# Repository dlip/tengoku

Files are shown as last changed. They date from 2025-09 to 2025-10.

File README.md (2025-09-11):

# Tengoku

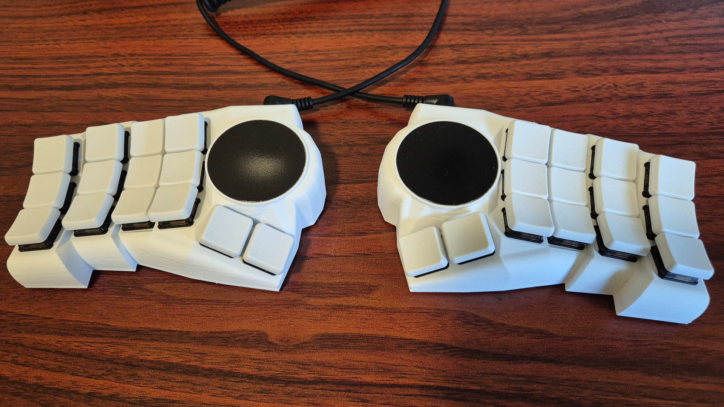
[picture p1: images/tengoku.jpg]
tengoku


28 Key Keyboard with dual trackpads made using [Cosmos Keyboard Generator](https://ryanis.cool/cosmos/beta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)

[Build Guide](/build.md)

## Media

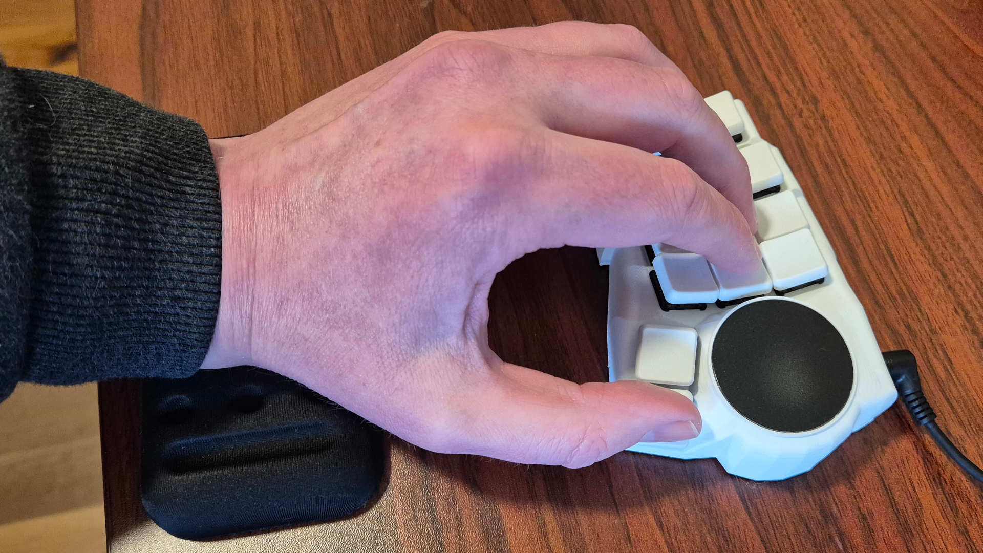
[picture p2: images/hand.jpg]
Hand size


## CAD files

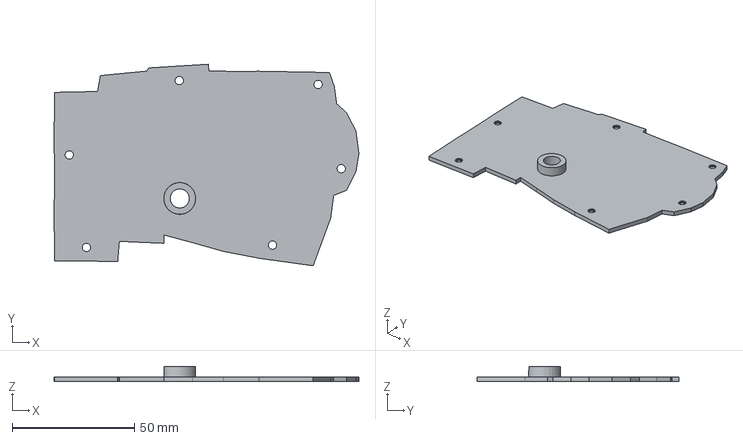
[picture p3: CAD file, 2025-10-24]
cad/tengoku-plateleft-with-mount-hole.step
124.7 x 82.4 x 6.30 mm

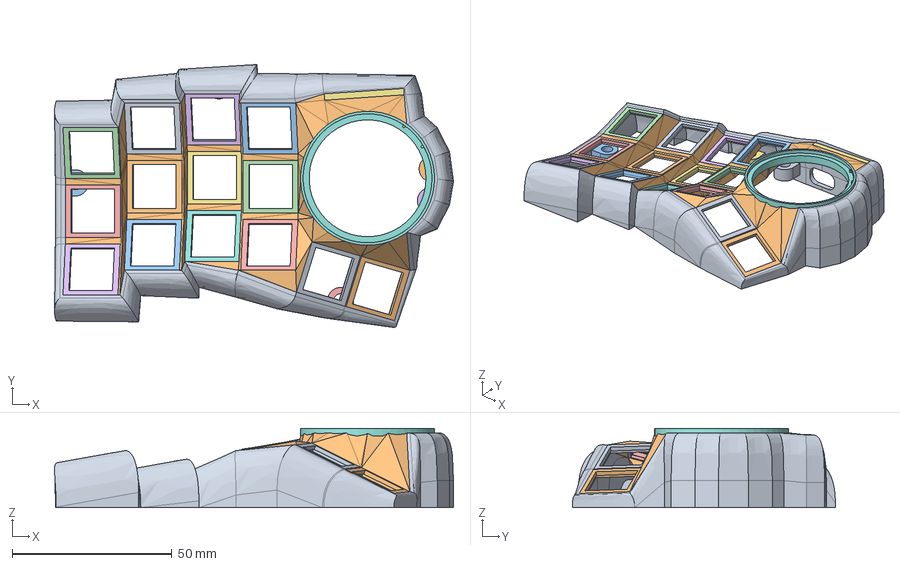
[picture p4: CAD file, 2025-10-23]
cad/tengoku.FCStd
125.0 x 82.4 x 24.9 mm
Walls001
Web001
Switch Holders017
Switch Holders018
Switch Holders019
Switch Holders020
Switch Holders021
Switch Holders022
Switch Holders023
Switch Holders024
Switch Holders025
Switch Holders026
Switch Holders027
Switch Holders028
Switch Holders029
Switch Holders030
Switch Holders031
Switch Holders032
Screw Attachments009
Screw Attachments010
Screw Attachments011
Screw Attachments012
Screw Attachments013
Screw Attachments014
Screw Attachments015
Screw Attachments016

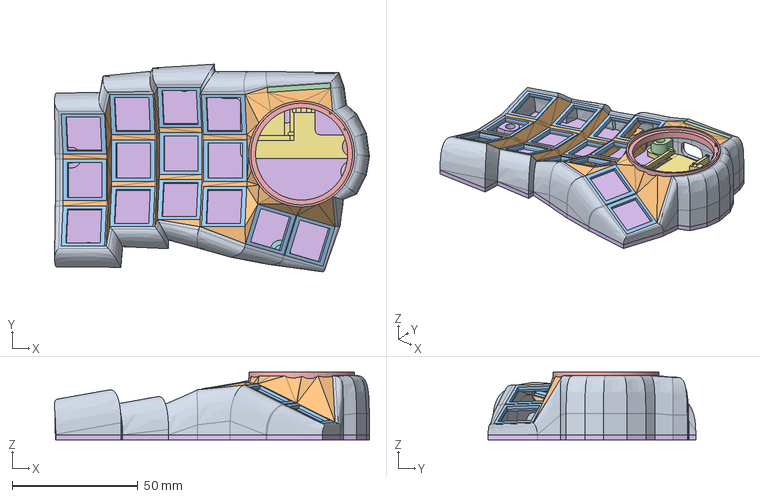
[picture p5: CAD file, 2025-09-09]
cad/tengokuleft.step
125.0 x 82.4 x 26.9 mm

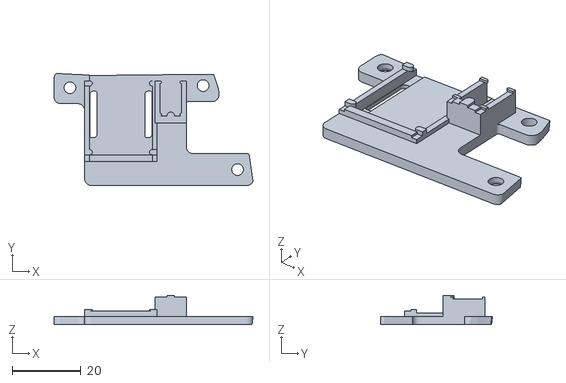
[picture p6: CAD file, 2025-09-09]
cad/tengoku-holderleft.stl
57.9 x 32.6 x 8.50

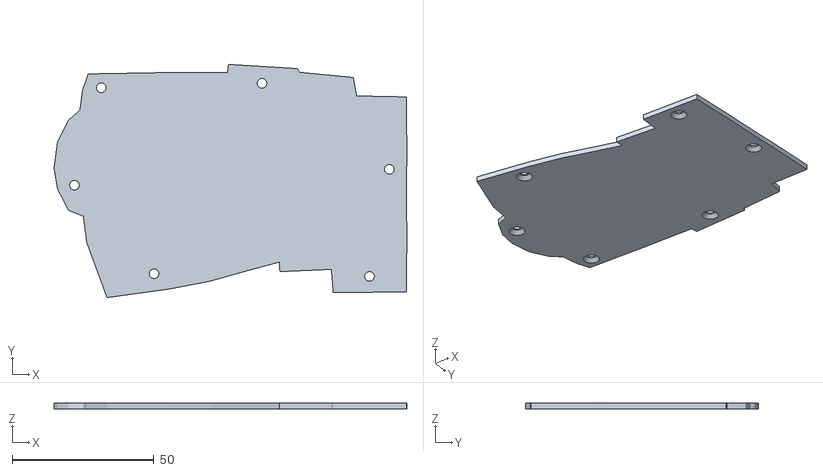
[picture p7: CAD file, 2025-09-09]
cad/tengoku-plateright.stl
124.7 x 82.4 x 2.00

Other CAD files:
cad/tengoku-plateright-with-mount-hole.step
cad/tengokuright.step
cad/tengoku-plateleft.stl
cad/tengoku-holderright.stl
cad/tengoku-caseleft-shifted-mcu-screw-attachment.step
cad/tengoku-caseright-shifted-mcu-screw-attachment.step
cad/tengoku-caseleft-shifted-mcu-screw-attachment.stl
cad/tengoku-caseright-shifted-mcu-screw-attachment.stl
cad/tengoku-plateleft-with-mount-hole.stl
cad/tengoku-plateright-with-mount-hole.stl

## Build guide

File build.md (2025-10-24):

# Tengoku Build

## Parts

| Name | Qty | Link |
| --- | --- | --- |
| RP2040 Zero MCU | 2 | <https://www.aliexpress.com/item/1005007650325892.html> |
| M3 Heat Inserts 5mm Length, OD 4.5mm | 16  | <https://www.aliexpress.com/item/1005008897571758.html> |
| M3 x 5 mm Flat Head Screws for attaching the bottom plate | 10  | <https://www.aliexpress.com/item/1005007257158892.html> |
| M3 x 4 mm Flat Head Screws for attaching the microcontroller holder | 4 | <https://www.aliexpress.com/item/1005007257158892.html> |
| M3 x 8 mm Flat Head Screws for attaching microcontroller holder through bottom plate | 2 | <https://www.aliexpress.com/item/1005007257158892.html> |
| 1/4-20 8mm OD 6mm height Knurled Insert Nut (Optional) | 2 | <https://www.aliexpress.com/item/1005005225137961.html> |
| Choc v1 Switches (I like Ambients Nocturnal) | 28  | <https://keebd.com/products/ambients-silent-linear-nocturnal-choc-switches> |
| Choc v1 Keycaps | 28  | <https://chosfox.com/products/chocfox-cfx-choc-keycaps> |
| Cirque 40mm Trackpads TM040040-2024-302 with flat overlay | 2 | <https://au.mouser.com/ProductDetail/Cirque/TM040040-2024-302> |
| 1N4148 Diodes | 28  | <https://www.aliexpress.com/item/1005007807649334.html> |
| PJ-320A TRRS Connectors | 8 | <https://www.aliexpress.com/item/33029465106.html> |
| TRRS Cable | 8 | |
| Rubber or Silicone Feet | 8 | |
| 30 AWG Flexible Silicone Wire | 1 | <https://www.aliexpress.com/item/1005007256968315.html> |

## Printed Parts

Printed parts are in the [cad](./cad/) folder. Printing the .stl files will give you a complete keyboard, but I have also made files for the case where the mcu holder screws are raised 0.5mm since I found it wouldn't sit flush with my prints. Use the plate with the mount holes if adding the 1/4-20 for mounting with a smallrig/camera clamp.

## Wiring

### Tips

- [QMK Handwiring Guide](https://docs.qmk.fm/hand_wire)
- Avoid putting solder on the side of the MCU and try to avoid putting too much on the bottom or it won't slide in the holder
- Around 260c is a good temperature for melting in the heat inserts
- Solder the Cirque GND pin to the TRRS GND pin an the TRRS GND pin to the MCU

### Schematic

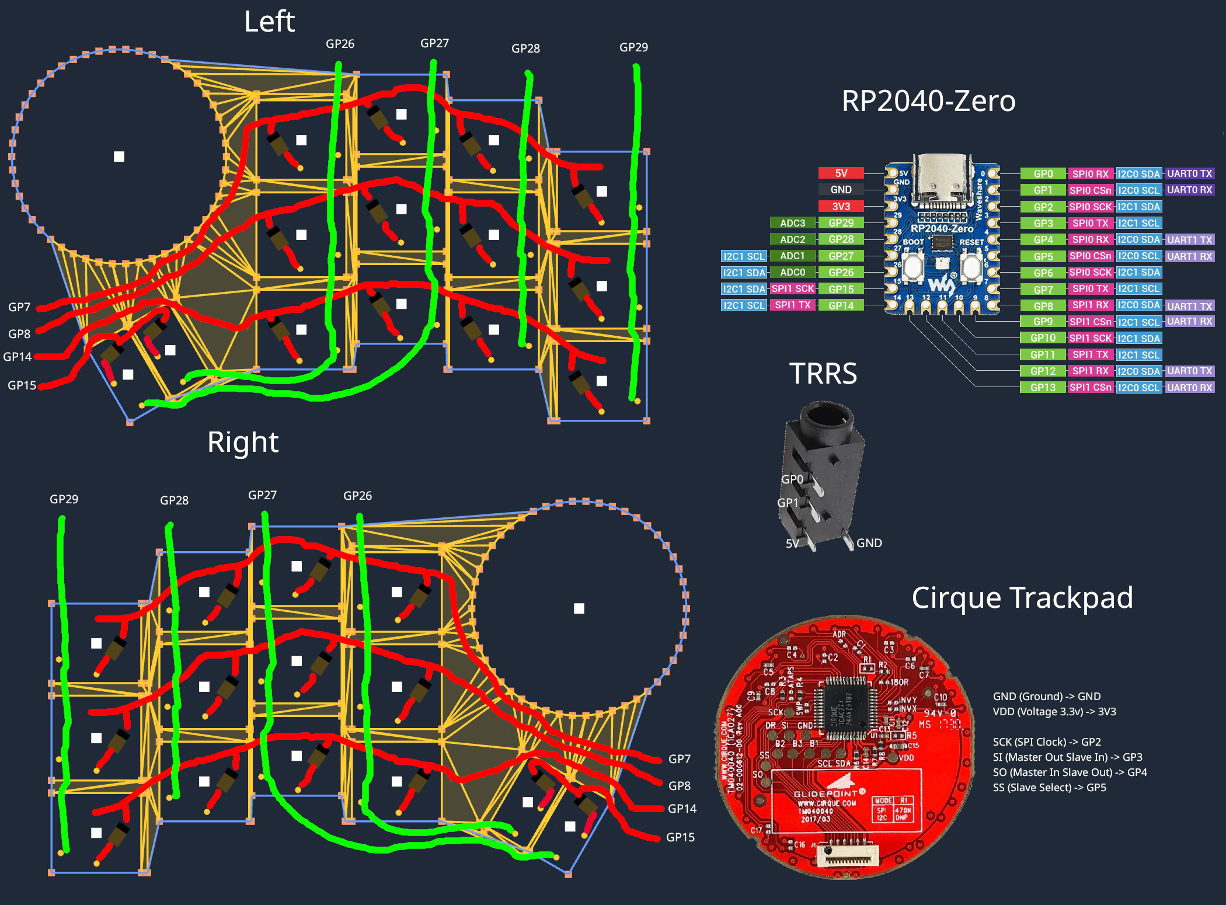
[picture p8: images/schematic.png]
Schematic


### Pics

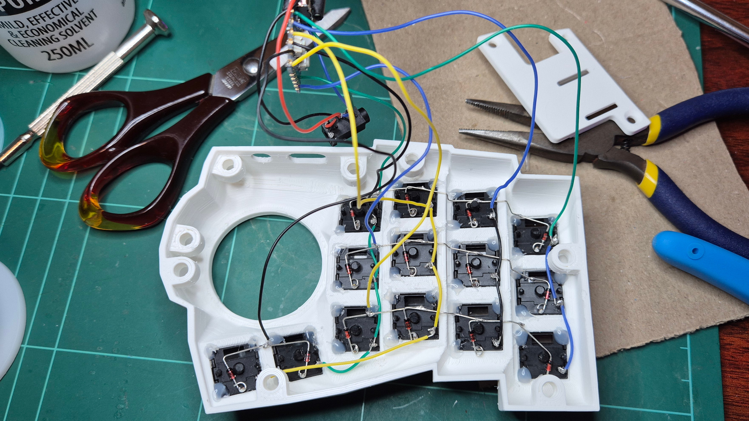
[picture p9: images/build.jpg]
Build


## Firmware

[QMK](https://github.com/dlip/qmk_firmware/tree/dlip/keyboards/dlip/tengoku)

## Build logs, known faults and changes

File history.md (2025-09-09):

<https://ryanis.cool/cosmos/beta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>

Remake

<https://ryanis.cool/cosmos/beta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>

Trackball
<https://ryanis.cool/cosmos/beta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>

Fix mcu mount
<https://ryanis.cool/cosmos/beta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>

tenting

<https://ryanis.cool/cosmos/beta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>

Print 2

<https://ryanis.cool/cosmos/beta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>

Fixes

<https://ryanis.cool/cosmos/beta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>

<https://ryanis.cool/cosmos/beta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>

<https://ryanis.cool/cosmos/beta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>

<https://ryanis.cool/cosmos/beta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>

<https://ryanis.cool/cosmos/beta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>

<https://ryanis.cool/cosmos/beta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>

15 tent

<https://ryanis.cool/cosmos/beta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>

<https://ryanis.cool/cosmos/beta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>

<https://ryanis.cool/cosmos/beta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>

<https://ryanis.cool/cosmos/beta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>

<https://ryanis.cool/cosmos/beta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>

<https://ryanis.cool/cosmos/beta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>

<https://ryanis.cool/cosmos/beta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>

<https://ryanis.cool/cosmos/beta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>

<https://ryanis.cool/cosmos/beta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>

Print 3

<https://ryanis.cool/cosmos/beta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>

Fix blank key
<https://ryanis.cool/cosmos/beta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>

screws

<https://ryanis.cool/cosmos/beta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>

<https://ryanis.cool/cosmos/beta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>

<https://ryanis.cool/cosmos/beta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>

<https://ryanis.cool/cosmos/beta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>

<https://ryanis.cool/cosmos/beta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>

Shape key
<https://ryanis.cool/cosmos/beta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>

Fix screws
<https://ryanis.cool/cosmos/beta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>

<https://ryanis.cool/cosmos/beta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>

<https://ryanis.cool/cosmos/beta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>

Print 4

<https://ryanis.cool/cosmos/beta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>

plate thickness

<https://ryanis.cool/cosmos/beta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>

Cirque again

<https://ryanis.cool/cosmos/beta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>

Horizontal thumbs

<https://ryanis.cool/cosmos/beta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>

Tweak thumbs

<https://ryanis.cool/cosmos/beta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>

mcu

<https://ryanis.cool/cosmos/beta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>

fix holes

<https://ryanis.cool/cosmos/beta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>

Add screws

<https://ryanis.cool/cosmos/beta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>

Fix holes

<https://ryanis.cool/cosmos/beta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>

Lower height

<https://ryanis.cool/cosmos/beta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>

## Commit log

2025-09-11 Add schematic
2025-09-11 Add cad
2025-10-23 Add FCStd
    [tengoku.FCStd]
2025-10-24 Add plate with mount hole
    [tengoku-plateleft-with-mount-hole.step, tengoku-plateleft-with-mount-hole.stl, tengoku-plateright-with-mount-hole.step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]
